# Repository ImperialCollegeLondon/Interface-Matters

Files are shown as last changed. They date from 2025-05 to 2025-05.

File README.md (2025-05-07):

# Interface Matters
This is the repository for paper "**Interface Matters: Comparing First and Third-Person Perspective Interfaces for Bi-Manual Robot Shoe Lacing Behavioural Cloning**" accepted for publication on the 2025 IEEE International Conference on Robotics and Automation (ICRA).

## Demo: Shoe Lacing with GuMi
This demo tests GuMi under the scenario of shoe lacing. The video is replayed at 16x speed.

https://github.com/user-attachments/assets/7c5b7bba-3eb4-41c3-b969-fab2bfed8b5f

## Repo structure
The repository is organized as follows:
- [`gumi/`](gumi/): Contains the 3D models and assembly instructions for the GuMi teleoperation device.
- [`gumi_docker/`](gumi_docker/): Contains the ROS package for GuMi, including the scripts for calibration to publishing ROS commands.

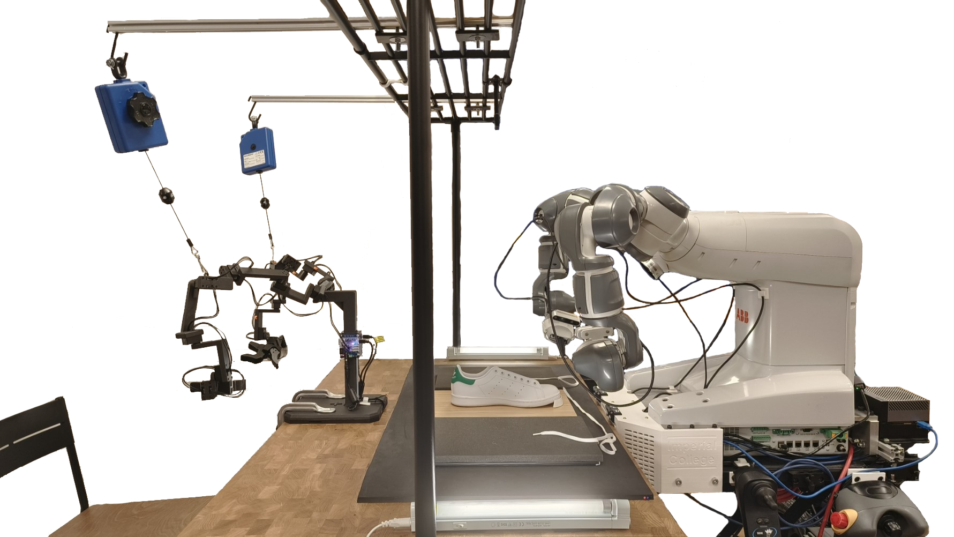
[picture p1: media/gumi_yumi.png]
GuMi Logo


**Note**: This device relies on the [**Externally Guided Motion (EGM)**](https://library.e.abb.com/public/726b2f1b18b24edd8599bfd4eb885553/3HAC073319%20AM%20Externally%20Guided%20Motion%20RW6-en.pdf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) library from ABB. Please check first if EGM is available in your Robotware.

## Acknowledgements
We would like to thank the authors of the following projects for their open-source contributions:
- [GELLO](https://wuphilipp.github.io/gello_site/)
- [kth-yumi](https://github.com/kth-ros-pkg/yumi)
- [abb_robot_driver](https://github.com/ros-industrial/abb_robot_driver)
- [abb_robot_driver_interfaces](https://github.com/ros-industrial/abb_robot_driver_interfaces)
- [abb_libegm](https://github.com/ros-industrial/abb_libegm)
- [abb_librws](https://github.com/ros-industrial/abb_librws)
- [abb_egm_rws_managers](https://github.com/ros-industrial/abb_egm_rws_managers)

## Citation
```
@inproceedings{luo2025interface,
    title={Interface Matters: Comparing First and Third-Person Perspective Interfaces for Bi-Manual Robot Shoe Lacing Behavioural Cloning},
    author={Haining Luo, Rodrigo Chacon Quesada, Fernando Estevez Casado, Nico Lingg, Yiannis Demiris},
    booktitle={2025  IEEE International Conference on Robotics and Automation (ICRA)},
    pages={in print},
    year={2025},
    organization={IEEE}
}
```

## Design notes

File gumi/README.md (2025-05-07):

## GuMi: A teleoperation device for the dual-arm robot YuMi

<p align="center">
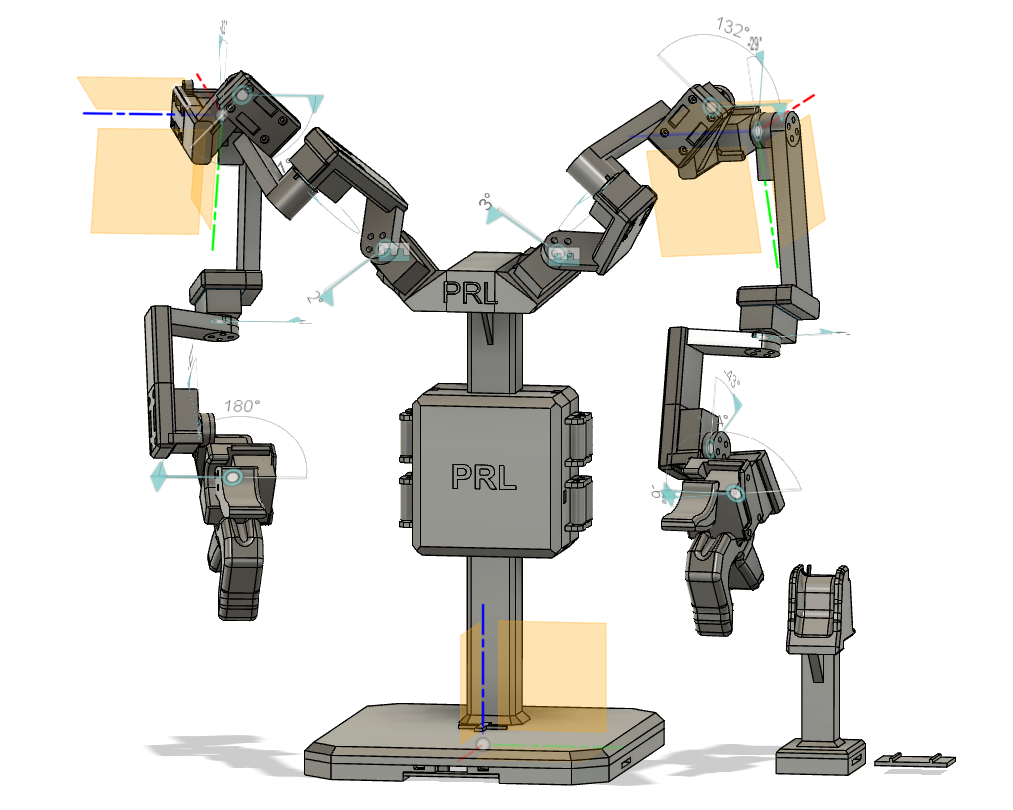
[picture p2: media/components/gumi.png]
GuMi Logo
    
</p>

This folder contains the stl files and assembly instructions for the GuMi teleoperation device. The complete device is composed of the following 3D printed parts:

- 1x [Base](base/README.md)
- 2x [H2D2 Support](h2d2_support/README.md)
- 1x [H2D2 Cover (Optional)](h2d2_cover/README.md)
- 2x [Arm](arm/README.md)
- 2x [Gripper](gripper/README.md)

Additionally, the following hardware is required:
- 2x H2D2 with Power Hub Board
- 14x Dynamixel XL330-M288-T
- 2x Dynamixel XL330-M077-T
- 2x RS PRO 24W AC/DC Adapter 5V DR Output (or equivalent power supply)
- 2x Aeromotive RB2 Tool Balancer (0.5-0.9kg)
- 1x Kennedy 200mm F-Clamp (or equivalent clamp)

You can start from the [Base](base/README.md).

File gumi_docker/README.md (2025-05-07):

# GuMi Scripts
This folder contains dockerfied environment for GuMi. `gumi_ros` package communicates with GuMi and publishes the commands to the robot.  

## EGM
GuMi ROS relies on [Externally Guided Motion (EGM)](https://search.abb.com/library/Download.aspx?DocumentID=3HAC073319-001&DocumentPartId=) from ABB to control YuMi. Check with your local ABB representative to obtain the EGM license for YuMi.
To install the EGM package on the robot controller 
1. Connect YuMi to a Windows device running RobotStudio. Backup the current controller before proceeding.
1. Navigate to Installation->RobotWare->YuMi Controller->Next->Add-> select EGM license file. Be aware that this will remove all existing programs on the robot controller.
1. The robot controller will restart after the installation.

## Configure the drivers for YuMi
GuMi ROS relies on `abb_robot_driver` for communication with the robot. In case this is not completed already, following the steps below to configure the drivers:
1. Install the `state_machine` add-on on the robot controller through RobotStudio. 
   - The `state_machine` add-on was once removed from RoboApps. In case this happens again, download the add-on from [here](https://github.com/ros-industrial/abb_libegm/files/10754679/ABB.StateMachine-1.1.zip).
1. Configure YuMi in RobotStudio 
    - The Communication Protocols: make sure the remote addresses for both arms and UCdevice are the address of the remote machine. Use the same remote port for ROB_L and UCdevice and leave ROB_R alone.
    - Add YuMi gripper tasks to the robot controller. 
        - Find the RAPID code for the gripper tasks in `yumi_gripper_driver/RAPID/`.
        - Follow the [instructions](https://github.com/kth-ros-pkg/yumi/wiki/Firmware#grippers-and-cameras) from KTH to add the gripper tasks to the robot controller (the RAPID codes are adapted from [their repo](https://github.com/kth-ros-pkg/yumi/wiki), please visit for more information about YuMi).

## Calibrate GuMi
The motor positions of the robot need to be calibrated before running the package. The calibration is done by moving the robot to a known position and recording the motor positions. Once you finish, pop the values to the `gumi_ros/scripts/gello.yaml` file. 

## Running the package
1. Pull YuMi drivers:
    `make pull-drivers`
1. Build the Docker image:
    `make build`
1. Build the ROS packages:
    `make compile`
1. Start YuMi positional controller:
    `make pos-controller`
1. Start GELLO interface:
    `make gumi`
    - YuMi will start moving to and stop at the grasp configuration. Now you can check and make sure that GELLO joints are aligned with YuMi. You can hit enter once you are satisfied with the alignment.
    - The robot will move to align with the GELLO model. Once the robot stops, you can hit enter to start the teleoperation.
1. Move the robot back to the grasp position:
    `make yumi-go-grasp`
1. Move the robot to the home position:
    `make yumi-go-home`

<!-- 
# Teleoperation

## Constructing Gello models
TODO: upload the `read_urdf.py` script
1. Use the `read_urdf.py` script to find the shortest link and compare it with the length of the motors
1. Decide on the scale of the model and set the scale in the `read_urdf.py` script
1. Use the `read_urdf.py` script to print the joint Cartesian positions relative to the upper stream joint frame.
    * Set all joints to zero so that it is easier to move from one joint to the next
1. Construct / download models of the motors
1. Set motor positions to the joint positions obtained from the `read_urdf.py` script
    * Double check that the motor axis is the same as the joint axis in RViz
1. Build model holders and align them with the motors
1. Connect the motor holders
1. Add virtual joints to the motor holders

## Gravity Compensation
1. Cannot be done the same as in Gello. YuMi links do not have square angles and the gravity compensation is not as simple as in Gello
1. [Aloha 2](https://aloha-2.github.io/) uses spring balancers to compensate for the gravity as in this [photo](https://aloha-2.github.io/assets/workcell_render.png).
1. The spring balancers they used should be this [AER-RB2](https://www.aero-motivedirect.com/Products/Retractors/?cart_id=UQRuD5LLhNl6haXxaNbuuhn6wPYBaSZ2&user_id=) from Aero-Motive. The company only ships to US addresses. Purchase link [here](https://www.cromwell.co.uk/shop/cutting-tools/tool-balancers/rb2-tool-balancer-0-5-0-9-kg/p/CTL2807800A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) from Cromwell. Datasheet [here](https://www.aero-motivedirect.com/Products/Positioners/PDF/Balancers%20and%20Tool%20Support%20Catalog.pdf)
1. The RB2 balancers are a bit tricky to set up. It needs to be pulled very hard when increasing the tension.

 -->

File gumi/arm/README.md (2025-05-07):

## Arm

<p align="center">
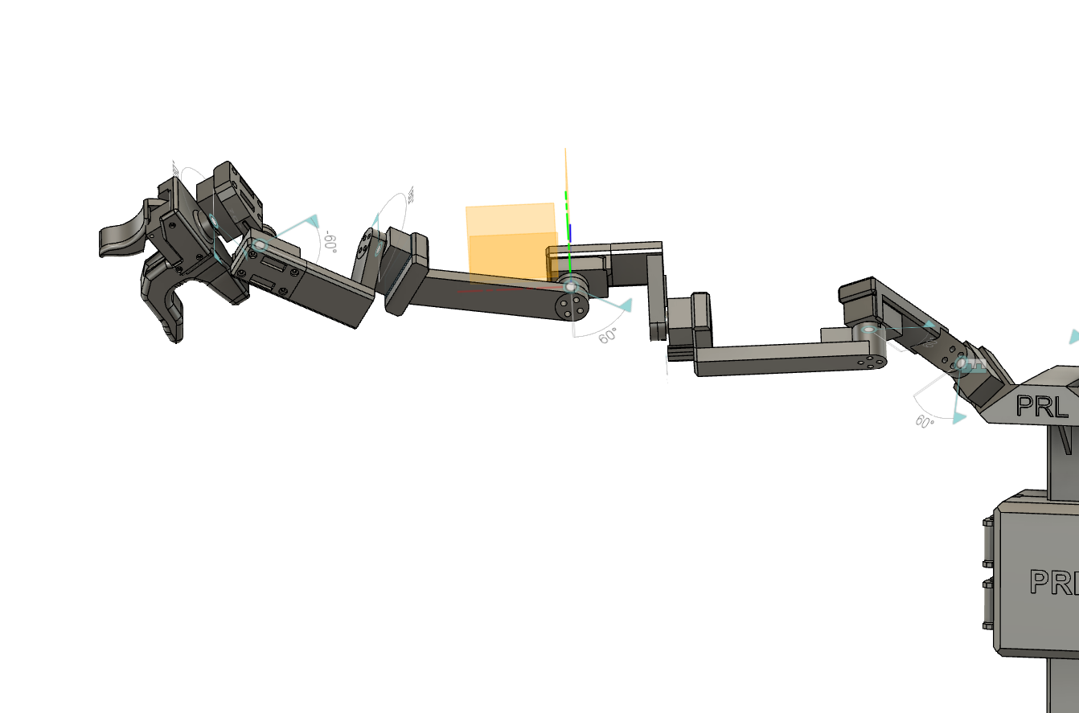
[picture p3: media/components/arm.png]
Arm
    
</p>

This folder includes the 3D models and assembly instructions for the 2 arms of the GuMi teleoperation device. 

### Components
- 1x Link 1-6 (Link 7 is combined with the gripper)
- 7x Dynamixel XL330-M288-T

### Assembly Instructions
1. Start from the base of the arm, install the Dynamixel XL330-M288-T and the links in order.
2. Connect the Dynamixel XL330-M288-T motors using the provided cables. The connected ports do not matter.
3. Move on to install the [Gripper](../gripper/README.md) on the end of the arm.

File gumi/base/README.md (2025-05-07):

## Base

<p align="center">
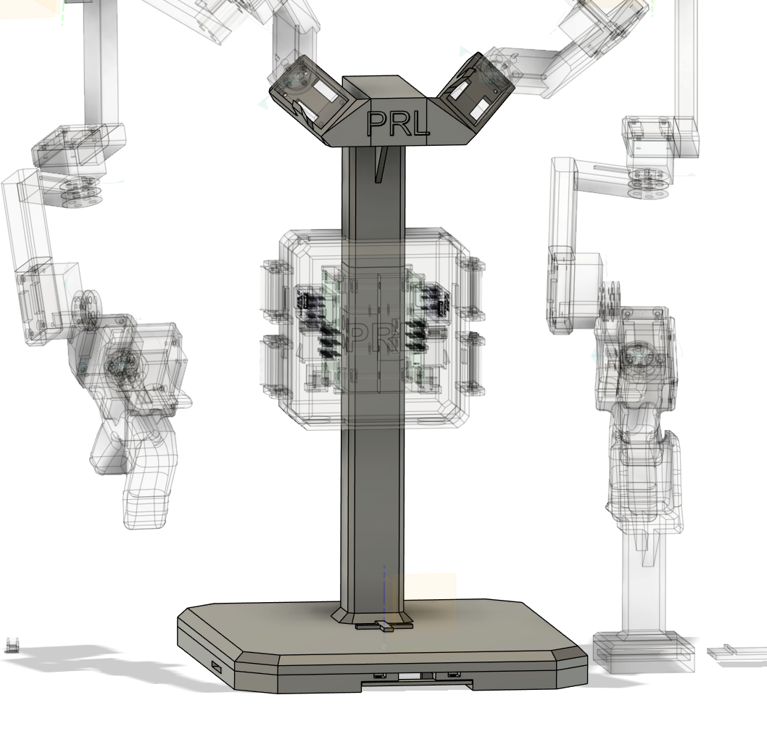
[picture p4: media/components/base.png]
Base Component
    
</p>

The Base component provides support for the two arms, route for the wires at the bottom, and cursor for the base centre. The H2D2 support is mounted on the middle of the base. The wiring box is press-fitted to cover the wires and the H2D2 boards. 

### Components
- 1x BaseBottom
- 1x BaseTop
- 4x M3x15 screws
- 4x M3 nuts

### Assembly Instructions
1. (Optional) Place the BaseBottom side up, glue the two BaseSupports to the BaseBottom in the same orientation as shown in the image. Fit the H2D2 cables though the BaseSupports and Screw the BaseSupportBridge (The BaseSupports are for asthetic purposes only and not necessary for the structure of the base).
2. Place the BaseTop on top of the BaseBottom and align the holes. Insert 4 M3x15 screws through the holes and knot the screws with M3 nuts.
3. Move on to install the [H2D2 Supports](../h2d2_support/README.md).

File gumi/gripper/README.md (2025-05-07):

## Gripper

The gripper design is a slightly modified version from the original GELLO project. Please refer to the [GELLO](https://wuphilipp.github.io/gello_site/) project for more information.

<p align="center">
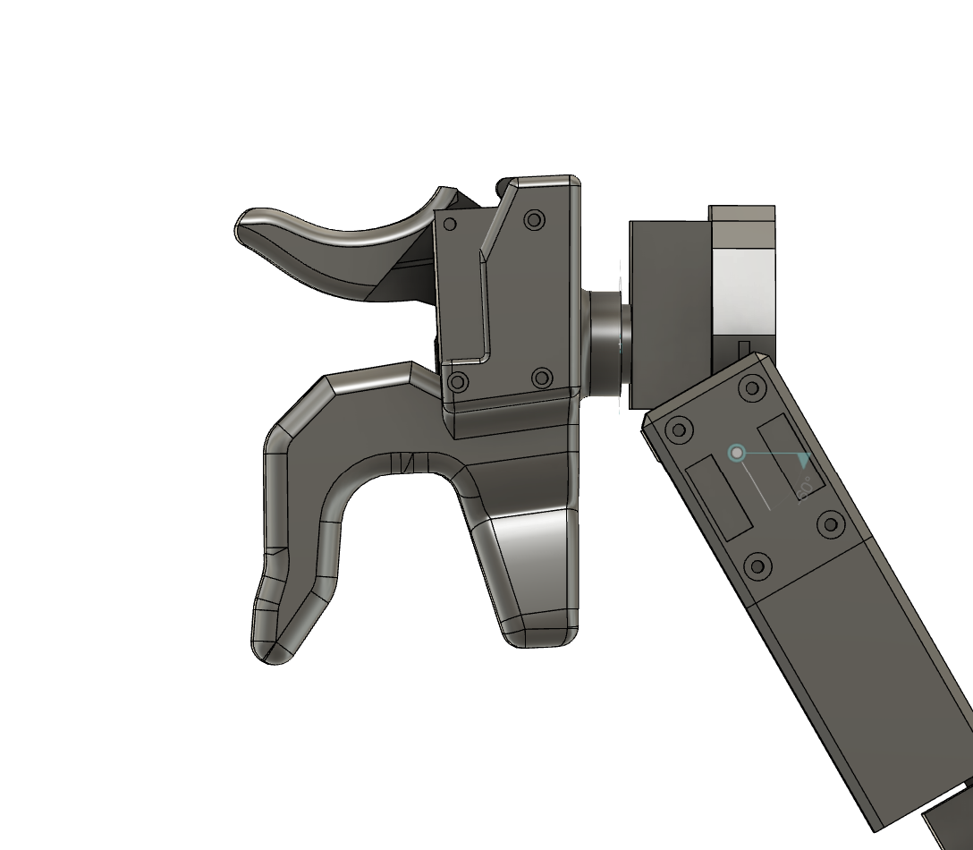
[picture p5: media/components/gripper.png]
Gripper
    
</p>

The Gripper component provides the ability to control the opening and closing of YuMi's SmartGripper. 

### Components
- 1x GripperBase
- 1x GripperTrigger
- 1x Dynamixel XL330-M077-T

### Assembly Instructions
1. Install the GripperBase on the end of the arm using the provided motor screws.
2. Install the Dynamixel XL330-M077-T on the GripperTrigger using the motor screws.
3. Connect the Dynamixel XL330-M077-T motor to the GripperBase using the motor screws.
4. Connect the motor provided cables to the Dynamixel XL330-M077-T motor with the Joint 7 motor.
5. (Optional) Move on to install the [H2D2 Cover](../h2d2_cover/README.md).

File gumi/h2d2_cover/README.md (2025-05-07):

## H2D2 Cover

<p align="center">
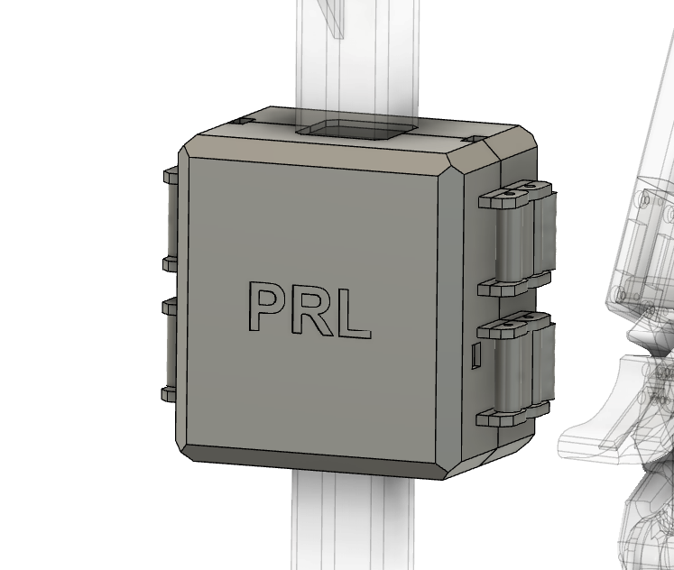
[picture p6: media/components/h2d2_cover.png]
Base Component
    
</p>

The H2D2Cover component seals electrical circuits and wires inside for the safety and aesthetics purposes. It is mounted on the middle of the base. 

### Components
- 1x H2D2CoverFront
- 1x H2D2CoverBack
- 4x H2D2CoverLatch
- 8x M3x20 screws

### Assembly Instructions
1. Place the latches on the H2D2CoverFront slots with the holes aligned as shown in the image. Insert screws through the holes of the H2D2CoverFront and H2D2CoverBack.
1. Place the H2D2CoverFront outside the H2D2Support and align the cable holes.
1. Close the latches to secure the H2D2CoverFront and H2D2CoverBack together.
1. Connect the USB and power cables to the H2D2 Power Hub Board.

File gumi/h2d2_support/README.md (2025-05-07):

## H2D2 Support

<p align="center">
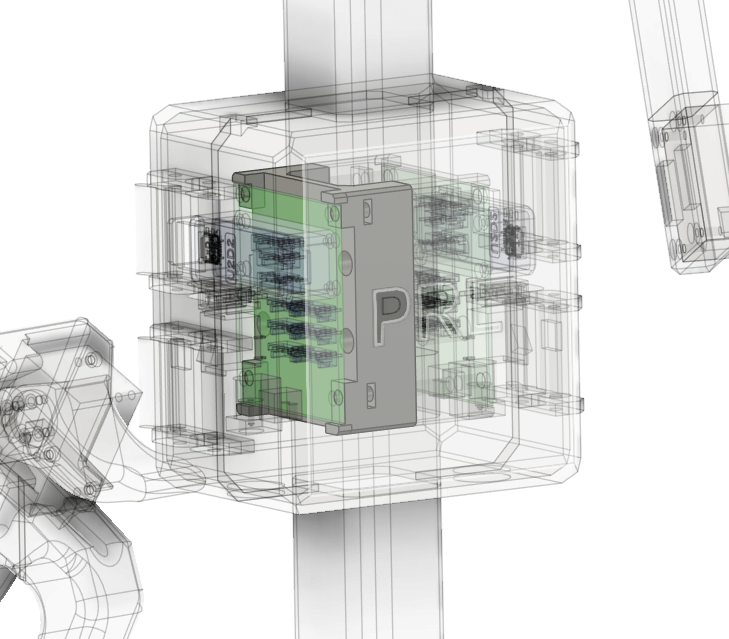
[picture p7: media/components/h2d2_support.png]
Base Component
    
</p>

The H2D2Support component provides support for the H2D2 boards. The H2D2Support is mounted on the middle of the base. 

### Components
- 2x H2D2Support
- 4x M3x15 screws
- 4x M3 nuts

### Assembly Instructions
1. Place the H2D2Support outside the Base piller and align the holes. 
1. Position the H2D2 Power Hub Board on the H2D2Support and align the holes.
1. Insert 4 M3x15 screws through the holes and knot the screws with M3 nuts.
1. If not using the H2D2 Cover, connect the USB and power cables to the H2D2 Power Hub Board.
1. Make sure the two USB cables connecting the H2D2s are connected to the device running GuMi scripts. If using a laptop, consider using a powered USB hub in case of insufficient motherboard power supply.
1. Move on to install the [Arms](../arm/README.md).

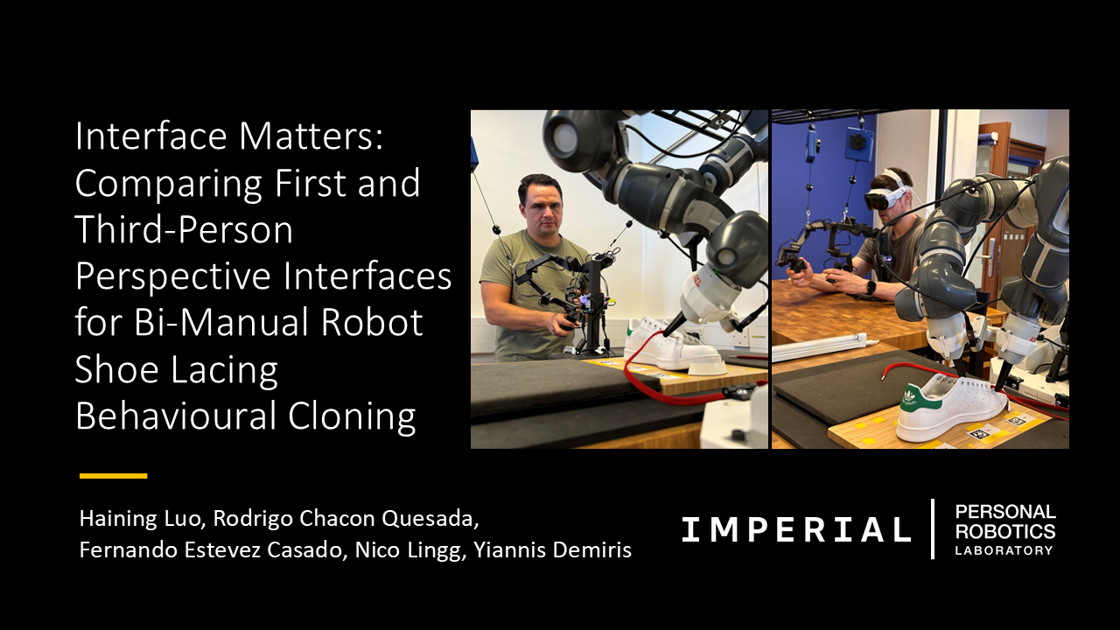
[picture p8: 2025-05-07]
media/cover_page.png

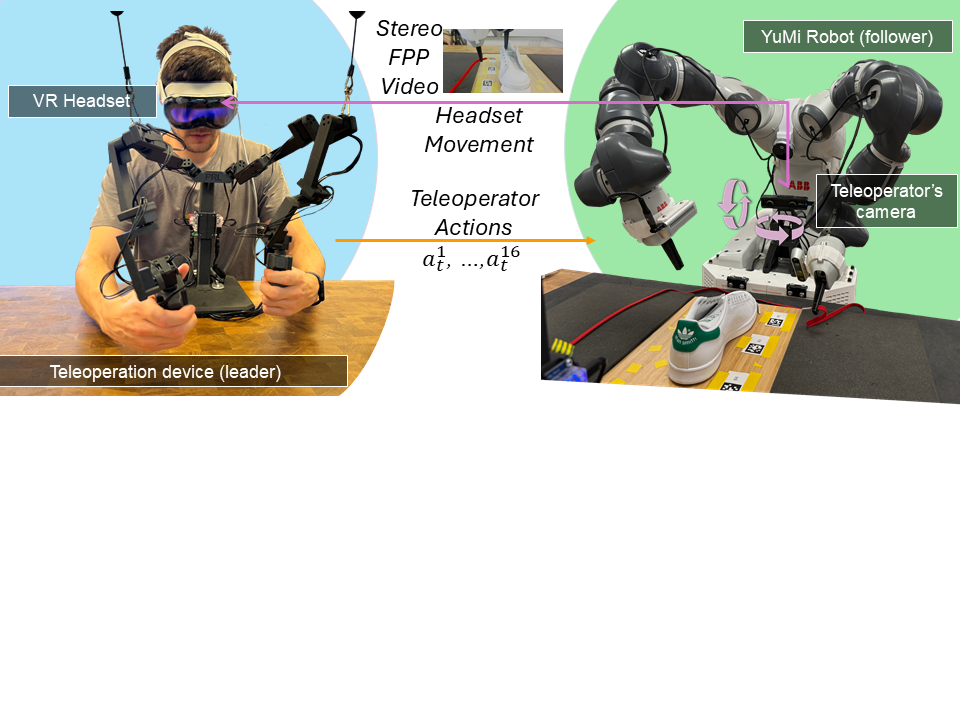
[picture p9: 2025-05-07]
media/ego_gumi_structure.png

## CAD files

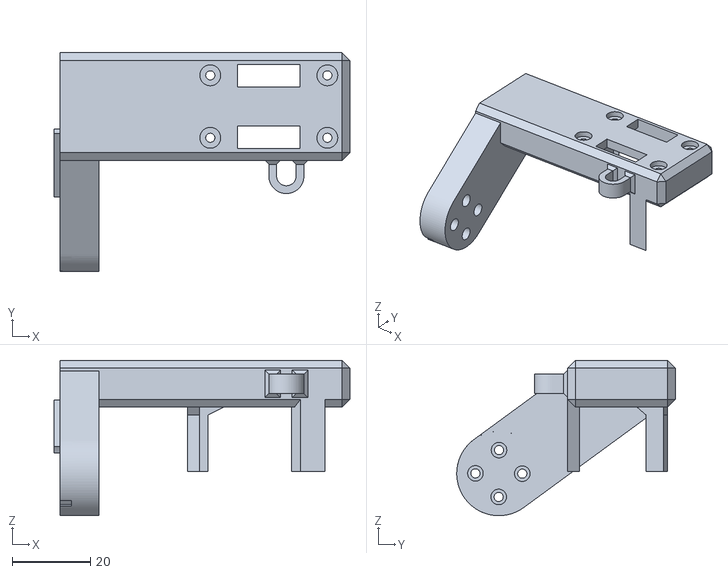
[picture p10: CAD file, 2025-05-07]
gumi/arm/stl/Link3.stl
75.8 x 56.0 x 39.8

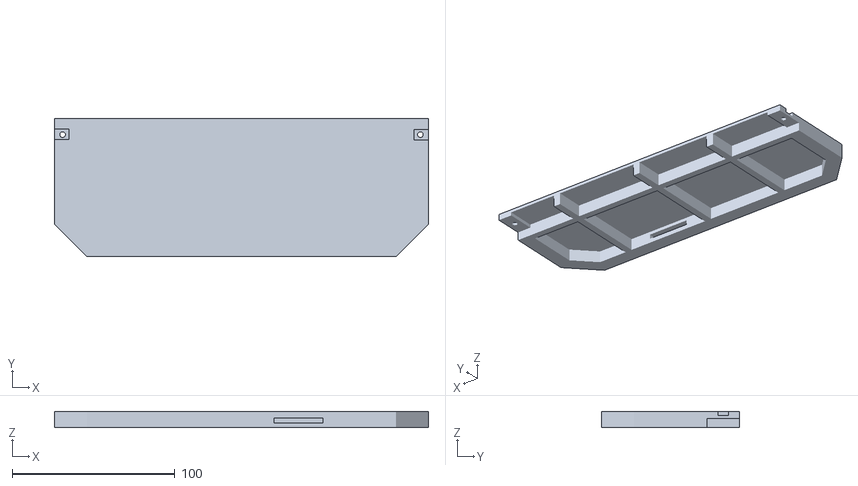
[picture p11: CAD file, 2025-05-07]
gumi/base/stl/BaseSupport.stl
230.0 x 85.0 x 10.0

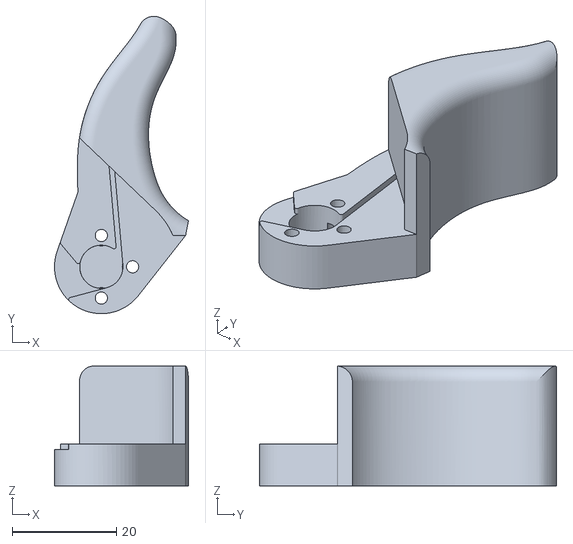
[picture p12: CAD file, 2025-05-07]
gumi/gripper/stl/GripperTrigger.stl
25.7 x 57.0 x 23.0

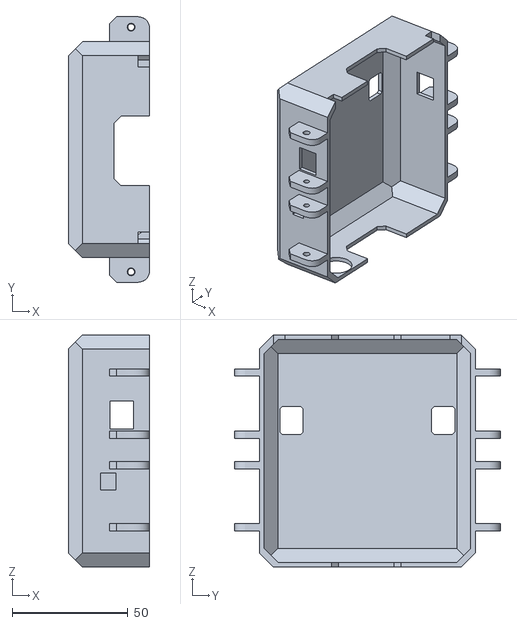
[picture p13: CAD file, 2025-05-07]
gumi/h2d2_cover/stl/H2D2CoverBack.stl
35.0 x 114.7 x 100.0

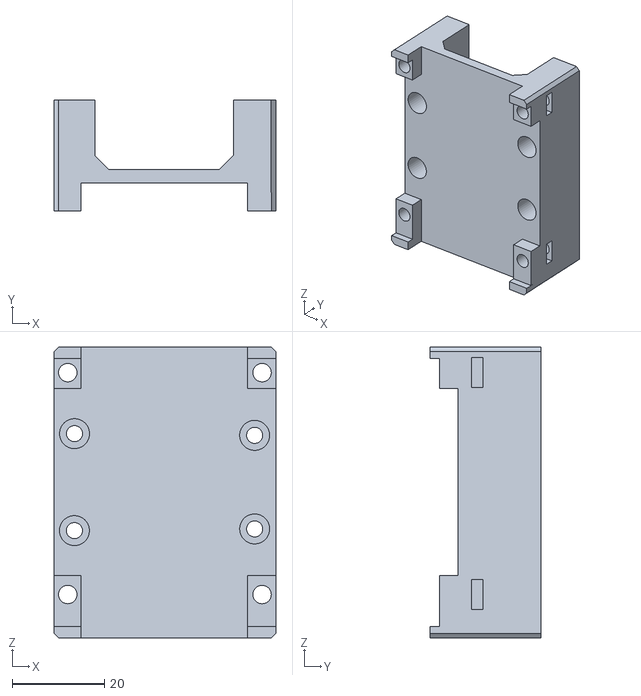
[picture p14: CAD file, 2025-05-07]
gumi/h2d2_support/stl/H2D2_Support.stl
48.0 x 24.0 x 63.0

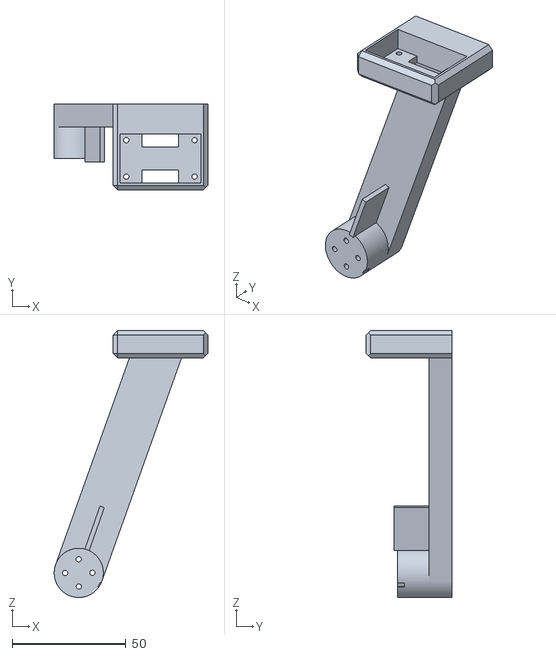
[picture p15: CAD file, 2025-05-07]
gumi/arm/stl/Link4.stl
67.5 x 37.6 x 117.3

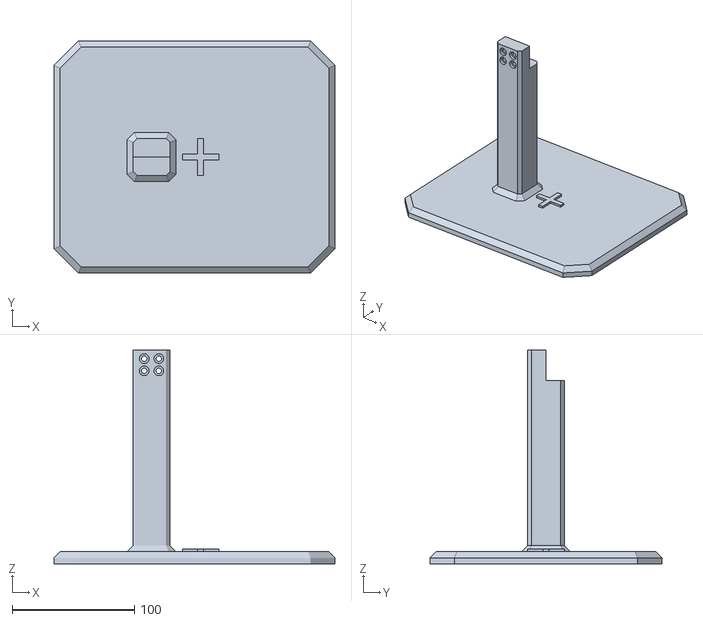
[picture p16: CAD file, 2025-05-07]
gumi/base/stl/BaseBottom.stl
230.0 x 190.0 x 175.0

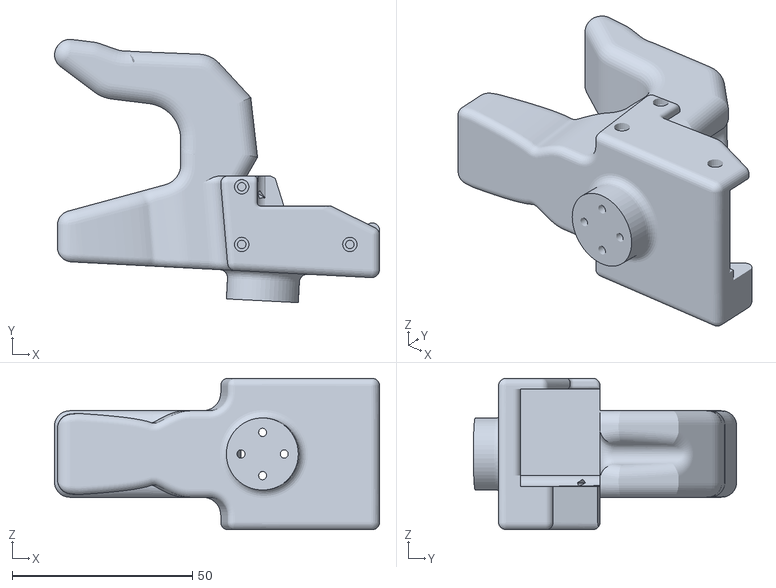
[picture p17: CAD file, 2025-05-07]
gumi/gripper/stl/GripperBase.stl
90.2 x 73.1 x 42.0

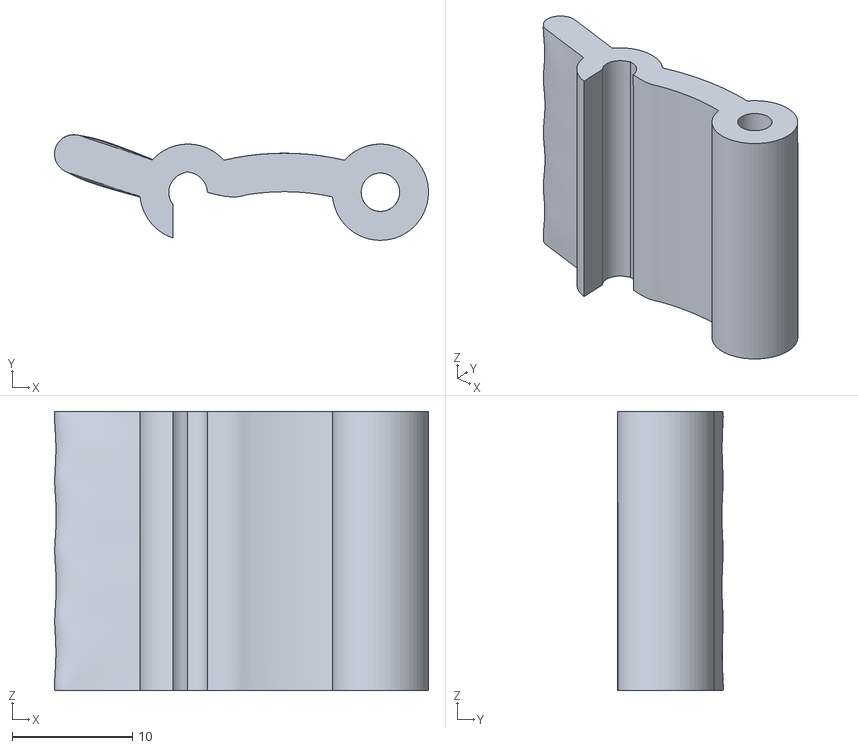
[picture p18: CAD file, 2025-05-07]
gumi/h2d2_cover/stl/H2D2CoverLatch.stl
31.1 x 8.79 x 23.2

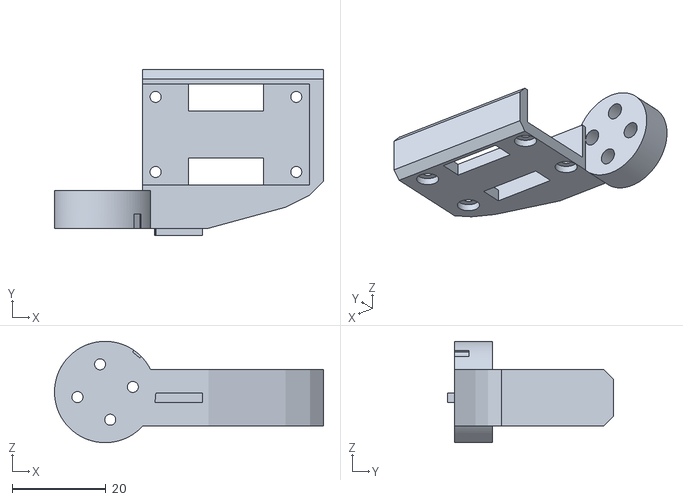
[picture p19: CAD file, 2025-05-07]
gumi/arm/stl/Llink6.stl
57.3 x 35.3 x 21.6

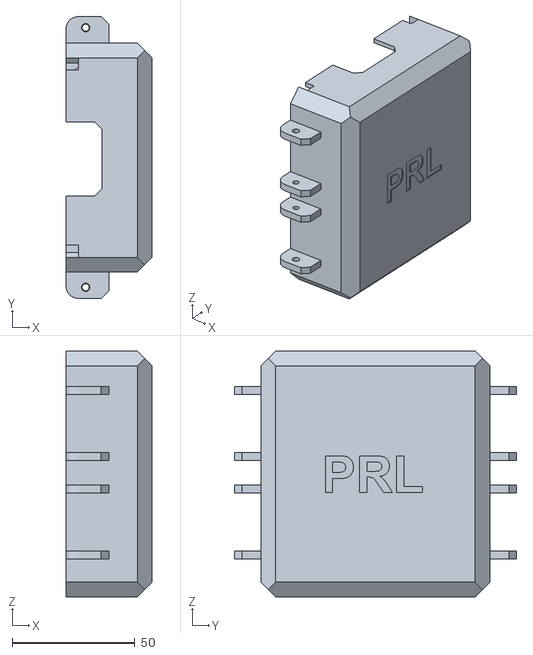
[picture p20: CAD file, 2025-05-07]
gumi/h2d2_cover/stl/H2D2CoverFront.stl
35.0 x 114.7 x 100.0

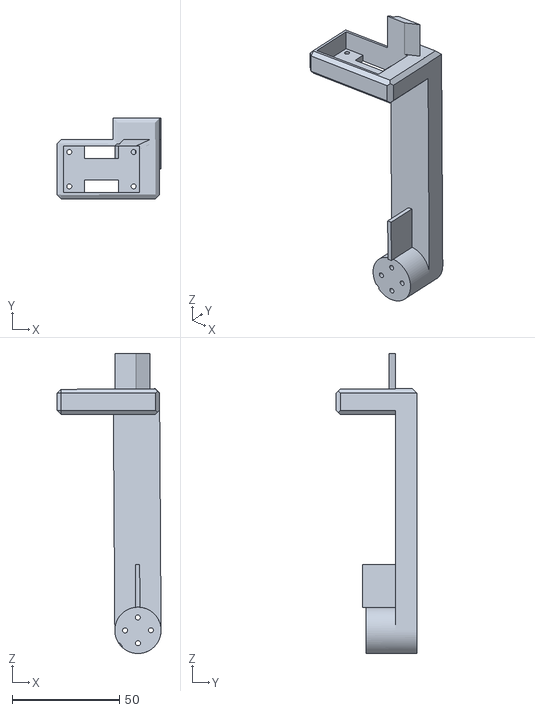
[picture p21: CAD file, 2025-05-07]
gumi/arm/stl/Link2.stl
48.6 x 37.6 x 139.9

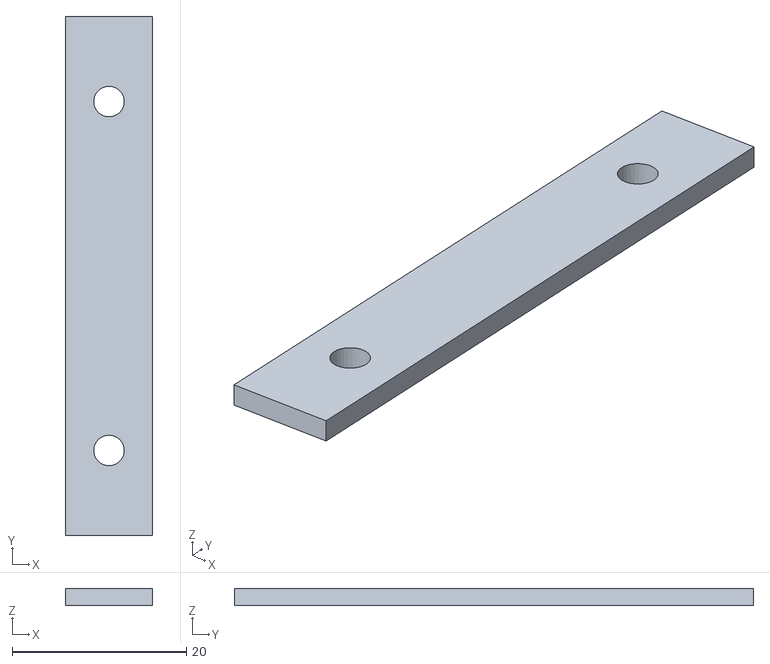
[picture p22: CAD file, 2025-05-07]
gumi/base/stl/BaseSupportBridge.stl
10.0 x 59.5 x 2.00

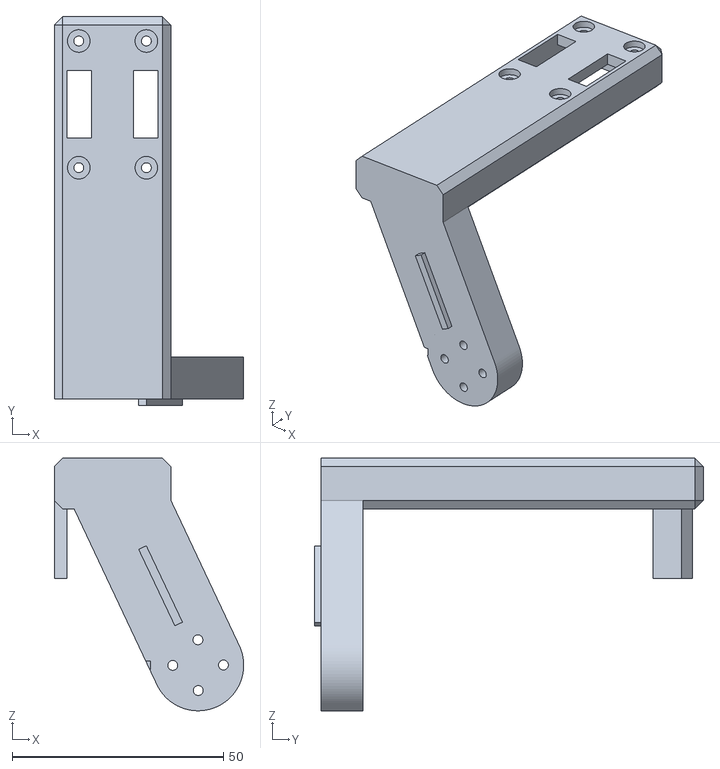
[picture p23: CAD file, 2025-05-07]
gumi/arm/stl/Link5.stl
44.8 x 92.1 x 59.8

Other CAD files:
gumi/base/stl/BaseSupport2.stl
gumi/base/stl/BaseTop.stl
gumi/arm/stl/Link1.stl

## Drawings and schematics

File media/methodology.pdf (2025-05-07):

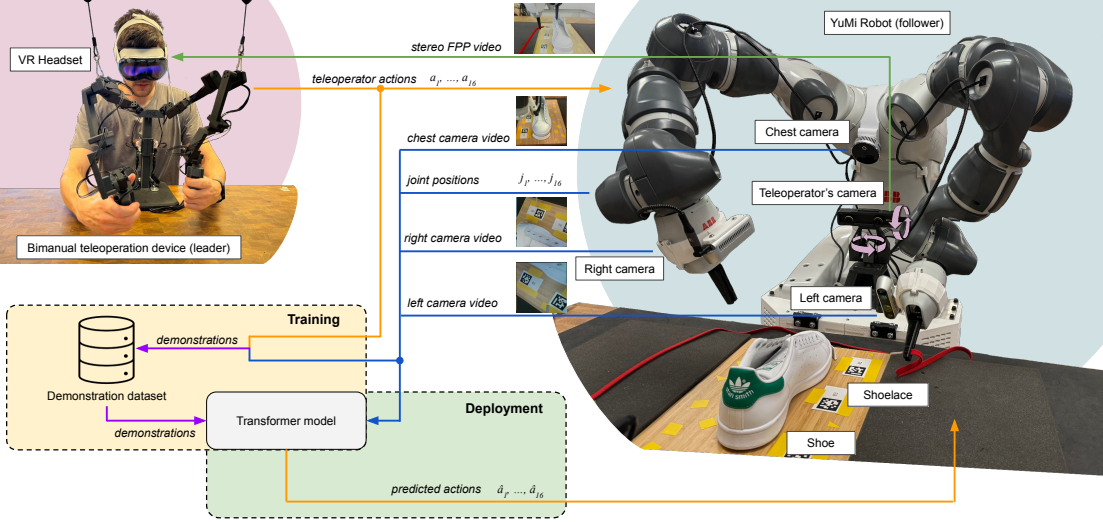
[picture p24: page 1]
VR Headset; Training; Right camera; Left camera; Transformer model; Deployment; Shoe; Shoelace; teleoperator actions; Demonstration dataset; predicted actions; Teleoperator’s camera; joint positions; demonstrations

YuMi Robot (follower)

stereo FPP video

Chest camera chest camera video

right camera video

Bimanual teleoperation device (leader)

left camera video

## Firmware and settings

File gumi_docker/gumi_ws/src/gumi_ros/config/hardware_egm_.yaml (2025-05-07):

# These settings must match:
# - Port numbers specified in the ABB robot controller's system configurations for EGM communication.
# - Names of the mechanical unit groups intended to be controlled by respective EGM communication channel.
egm:
  channel_1:
    port_number: 6510
    mech_unit_group: "rob_l"
  channel_2:
    port_number: 6512
    mech_unit_group: "rob_r"

# These settings must match:
# - Joint names extracted from the ABB robot controller.
# - The 'yumi_' prefix must match the nickname/identifier,
#   which is set in the corresponding launch file.
#
# See http://wiki.ros.org/joint_limits_interface for more info about available joint limits:
joint_limits:
  yumi_robl_joint_1:
    min_position: -2.84
    max_position: 2.84
    has_velocity_limits: true
    max_velocity: 1.570796327
    has_acceleration_limits: false
    max_acceleration: 0
  yumi_robr_joint_1:
    min_position: -2.84
    max_position: 2.84
    has_velocity_limits: true
    max_velocity: 1.570796327
    has_acceleration_limits: false
    max_acceleration: 0
  yumi_robl_joint_2:
    min_position: -2.4
    max_position: 0.65
    has_velocity_limits: true
    max_velocity: 1.570796327
    has_acceleration_limits: false
    max_acceleration: 0
  yumi_robr_joint_2:
    min_position: -2.4
    max_position: 0.65
    has_velocity_limits: true
    max_velocity: 1.570796327
    has_acceleration_limits: false
    max_acceleration: 0
  yumi_robl_joint_3:
    min_position: -2
    max_position: 1.29
    has_velocity_limits: true
    max_velocity: 1.570796327
    has_acceleration_limits: false
    max_acceleration: 0
  yumi_robr_joint_3:
    min_position: -2
    max_position: 1.29
    has_velocity_limits: true
    max_velocity: 1.570796327
    has_acceleration_limits: false
    max_acceleration: 0
  yumi_robl_joint_4:
    min_position: -4.9
    max_position: 4.9
    has_velocity_limits: true
    max_velocity: 1.570796327
    has_acceleration_limits: false
    max_acceleration: 0
  yumi_robr_joint_4:
    min_position: -4.9
    max_position: 4.9
    has_velocity_limits: true
    max_velocity: 1.570796327
    has_acceleration_limits: false
    max_acceleration: 0
  yumi_robl_joint_5:
    min_position: -1.43
    max_position: 2.3
    has_velocity_limits: true
    max_velocity: 1.570796327
    has_acceleration_limits: false
    max_acceleration: 0
  yumi_robr_joint_5:
    min_position: -1.43
    max_position: 2.3
    has_velocity_limits: true
    max_velocity: 1.570796327
    has_acceleration_limits: false
    max_acceleration: 0
  yumi_robl_joint_6:
    min_position: -3.89
    max_position: 3.89
    has_velocity_limits: true
    max_velocity: 1.570796327
    has_acceleration_limits: false
    max_acceleration: 0
  yumi_robr_joint_6:
    min_position: -3.89
    max_position: 3.89
    has_velocity_limits: true
    max_velocity: 1.570796327
    has_acceleration_limits: false
    max_acceleration: 0
  yumi_robl_joint_7:
    min_position: -2.84
    max_position: 2.84
    has_velocity_limits: true
    max_velocity: 1.570796327
    has_acceleration_limits: false
    max_acceleration: 0
  yumi_robr_joint_7:
    min_position: -2.84
    max_position: 2.84
    has_velocity_limits: true
    max_velocity: 1.570796327
    has_acceleration_limits: false
    max_acceleration: 0

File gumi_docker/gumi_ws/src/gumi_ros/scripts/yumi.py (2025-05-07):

from typing import Dict

import numpy as np
from math import sqrt
from random import random

import rospy
from std_msgs.msg import Float64, Float64MultiArray
from sensor_msgs.msg import JointState

from abb_robot_msgs.srv import TriggerWithResultCode
from abb_egm_msgs.msg import EGMState
from controller_manager_msgs.srv import SwitchController, SwitchControllerRequest
from abb_rapid_sm_addin_msgs.srv import GetEGMSettings, SetEGMSettings

# from base_robot import Robot


class YuMi():
    GRIPPER_TOLERANCE = 0.5 # mm
    TIME_TOLERANCE = 50
    GRIPPER_TIME_TOLERANCE = 5

    keep_egm_alive = False

    left_rapid_task = 'T_ROB_L'
    right_rapid_task = 'T_ROB_R'
    joint_names = ['yumi_robr_joint_1', 'yumi_robr_joint_2', 'yumi_robr_joint_3', 'yumi_robr_joint_4', 
                   'yumi_robr_joint_5', 'yumi_robr_joint_6', 'yumi_robr_joint_7', 'yumi_robl_joint_1', 
                   'yumi_robl_joint_2', 'yumi_robl_joint_3', 'yumi_robl_joint_4', 'yumi_robl_joint_5',
                   'yumi_robl_joint_6', 'yumi_robl_joint_7', 'gripper_r_joint', 'gripper_r_joint_m',
                   'gripper_l_joint', 'gripper_l_joint_m']
    
    # fix the left arm and gripper joints
    left_calc_states = [0, -2.2689, 2.3562, 0.5236, 0, 0.6981, 0]
    right_calc_states = [0, -2.2689, -2.3562, 0.5236, 0, 0.6981, 0]
    right_obs_states_old = [1.3764188289642334, -0.5266491770744324, -2.042018175125122, -0.25265806913375854, 0.39488810300827026, 1.015584111213684, 2.192312002182007]
    left_obs_states_old = [-1.2257874011993408, -0.4985324442386627, 1.980921745300293, -0.058894701302051544, -0.47677695751190186, 0.9440299868583679, -2.054021120071411]
    left_obs_states = [-0.720012903213501, -0.3579239249229431, 1.772327184677124, 
                       0.13136780261993408, -0.648350715637207, 1.1232486963272095, 
                       -1.8344221115112305]
    right_obs_states = [0.8814099431037903, -0.36250463128089905, -1.85231351852417, 
                        -0.028060272336006165, 0.606028139591217, 1.1636393070220947, 
                        1.9661468267440796]
    left_grasp_states = [-0.6087591438289535, -1.082181434487124, 1.8366249441652813, 
                         0.5307080841282654, 2.619130781460849, 0.30367070501132487, 
                         2.0107517372984773] 
    right_grasp_states = [0.6849933284549622, -1.0505161162309455, -1.9075465218907455, 
                          0.48255300503453435, 0.3831120013800615, -0.28755738199385494, 
                          1.3071448436156516]
    left_grasp_states2 = [-1.0771714448928833, -0.7815413475036621, 1.3724327087402344,
                            0.3715556263923645, 1.7982889413833618, 0.8510035872459412,
                            2.2453041076660156]
    right_grasp_states2 = [1.0602233409881592, -0.6867497563362122, -1.4237779378890991, 
                           0.3548184633255005, 4.543345928192139, 0.7604496479034424, 
                           -2.2329251766204834]

    command_pub = rospy.Publisher('/yumi/egm/joint_group_position_controller/command', Float64MultiArray, queue_size=10)
    left_gripper_pos_pub = rospy.Publisher('/yumi/gripper_l_position_cmd', Float64, queue_size=10)
    right_gripper_pos_pub = rospy.Publisher('/yumi/gripper_r_position_cmd', Float64, queue_size=10)
    left_gripper_cmd_pub = rospy.Publisher('/yumi/gripper_l_effort_cmd', Float64, queue_size=10)
    right_gripper_cmd_pub = rospy.Publisher('/yumi/gripper_r_effort_cmd', Float64, queue_size=10)

    def __init__(self):
        ### Prepare the robot for teleoperation
        self.start_egm_joint_client = rospy.ServiceProxy('/yumi/rws/sm_addin/start_egm_joint', TriggerWithResultCode)
        self.stop_egm_joint_client = rospy.ServiceProxy('/yumi/rws/sm_addin/stop_egm', TriggerWithResultCode)
        self.switch_controller_client = rospy.ServiceProxy('/yumi/egm/controller_manager/switch_controller', SwitchController)
        self.get_egm_settings = rospy.ServiceProxy("/yumi/rws/sm_addin/get_egm_settings", GetEGMSettings)
        self.set_egm_settings = rospy.ServiceProxy("/yumi/rws/sm_addin/set_egm_settings", SetEGMSettings)
        rospy.Subscriber('/yumi/egm/joint_states', JointState, self.yumi_states_sb, queue_size=1)
        rospy.Subscriber('/yumi/egm/egm_states', EGMState, self.egm_state_cb)
        rospy.Subscriber('/yumi/gripper_states', JointState, self.yumi_gripper_states_sb, queue_size=1)

        # get initial states
        states = rospy.wait_for_message('/yumi/egm/joint_states', JointState)
        self.left_arm_state = states.position[:7]
        self.right_arm_state = states.position[7:14]
        self.left_velocities = states.velocity[:7]
        self.right_velocities = states.velocity[7:14]
        gripper_states = rospy.wait_for_message('/yumi/gripper_states', JointState)
        self.left_gripper_state = gripper_states.position[0]*1000
        self.right_gripper_state = gripper_states.position[1]*1000
        rospy.sleep(0.5)
        print("YuMi wrapper initialized")

    def start_egm(self):
        response = self.start_egm_joint_client()
        if response.result_code == 1:
            print("EGM started")
        else:
            print("Failed to start EGM (code: {}, message: {})".format(response.result_code, response.message))
        rospy.sleep(0.5)
    
    def stop_egm(self):
        response = self.stop_egm_joint_client()
        if response.result_code == 1:
            print("EGM stopped")
        else:
            print("Failed to stop EGM (code: {}, message: {})".format(response.result_code, response.message))
        rospy.sleep(0.5)


    def egm_state_cb(self,msg):
        if not self.keep_egm_alive:
            return
        # check if EGM is off
        if msg.egm_channels[0].active == False:
            self.restarting = True
            rospy.loginfo('EGM is off. Restarting...')
            # call the service to start the EGM
            response = self.start_egm_joint_client()
            if response.result_code == 1:
                rospy.loginfo('EGM restarted successfully.')
            else:
                rospy.logerr('Failed to restart EGM (code: {}, message: {})'.format(
                    response.result_code, response.message))
            self.restarting = False

    def start_controllers(self):
        request = SwitchControllerRequest(start_controllers=['joint_group_position_controller'], 
                                        stop_controllers=[''], 
                                        strictness=1, 
                                        start_asap=False, 
                                        timeout=0.0)
        response = self.switch_controller_client(request)
        if response.ok:
            print("Controller started")
        else:
            print("Failed to restart Controllers (code: {}, message: {})".format(response.result_code, response.message))
        rospy.sleep(0.5)

    def change_max_speed(self, task, max_speed_deviation):
        # reset max velocity
        current_settings = self.get_egm_settings(task=task)
        settings = current_settings.settings
        settings.activate.max_speed_deviation = max_speed_deviation # degs
        settings.run.pos_corr_gain = 1 # 0 for pure velocity control
        response = self.set_egm_settings(task=task, settings=settings)
        if response.result_code == 1:
            print("Max speed deviation set to: ", max_speed_deviation)
        else:
            print("Failed to set max speed deviation (code: {}, message: {})".format(response.result_code, response.message))
        rospy.sleep(0.5)
    
    def _get_eef_pos(self) -> np.ndarray:
        return self.left_gripper_state + self.right_gripper_state

    def _get_gripper_pos(self) -> float:
        return self.left_gripper_state + self.right_gripper_state

    def get_joint_state(self):
        """Get the current state of the leader robot.

        Returns:
            T: The current state of the leader robot.
        """
        return list(self.left_arm_state) + list(self.right_arm_state)
    
    def get_joint_vel(self):
        """Get the current state of the leader robot.

        Returns:
            T: The current state of the leader robot.
        """
        return self.left_velocities + self.right_velocities

    def command_joint_state(self, joint_state: np.ndarray) -> None:
        """Command the leader robot to a given state.

        Args:
            joint_state (np.ndarray): The state to command the leader robot to.
        """
        controller_cmd = Float64MultiArray()
        controller_cmd.data = joint_state
        self.command_pub.publish(controller_cmd)

    def get_observations(self) -> Dict[str, np.ndarray]:
        joint_pos = self.get_joint_state()
        joint_vel = self.get_joint_vel()
        ee_force = self._get_eef_force()
        ee_pos_quat = self._get_eef_pos()
        ee_vel = self._get_eef_speed()
        gripper_pos = np.array([joint_pos[-1]])
        return {
            "joint_positions": joint_pos,
            "joint_velocities": joint_vel,
            "ee_pos_quat": ee_pos_quat,
            "ee_vel": ee_vel,
            "ee_force": ee_force,
            "gripper_position": gripper_pos,
        }

    
    def yumi_states_sb(self, msg):
        """ saves yumi states into this class """
        self.left_arm_state = msg.position[:7]
        self.right_arm_state = msg.position[7:14]
        self.left_velocities = msg.velocity[:7]
        self.right_velocities = msg.velocity[7:14]

    def yumi_gripper_states_sb(self, msg):
        """ saves yumi gripper states into this class """
        self.left_gripper_state = msg.position[0]*1000
        self.right_gripper_state = msg.position[1]*1000

    ###############
    ### Gripper ###
    ###############

    def wait_for_completion_gripper_l(self, log=True):
        """ pause until left gripper state within tolerance """
        time_start = rospy.Time.now()
        while not rospy.is_shutdown() and (rospy.Time.now()-time_start).to_sec()<self.GRIPPER_TIME_TOLERANCE:
            if self.check_completion_gripper_l():
                return True
            else:
                rospy.sleep(0.01)
        if log:
            rospy.logwarn("Gripper action timed-out. Not able to complete in "+str(self.GRIPPER_TIME_TOLERANCE)+'s')
        return False

    def wait_for_completion_gripper_r(self, log=True):
        """ pause until right gripper state within tolerance """
        time_start = rospy.Time.now()
        while not rospy.is_shutdown() and (rospy.Time.now()-time_start).to_sec()<self.GRIPPER_TIME_TOLERANCE:
            if self.check_completion_gripper_r():
                return True
            else:
                rospy.sleep(0.01)
        if log:
            rospy.logwarn("Gripper action timed-out. Not able to complete in "+str(self.GRIPPER_TIME_TOLERANCE)+'s')
        return False

    def check_completion_gripper_l(self):
        """ check if left gripper commands are within tolerance """
        error = sqrt((self.left_gripper_state-self.left_gripper_target)**2)
        return error<=self.GRIPPER_TOLERANCE

    def check_completion_gripper_r(self):
        """ check if right gripper commands are within tolerance """
        error = sqrt((self.right_gripper_state-self.right_gripper_target)**2)
        return error<=self.GRIPPER_TOLERANCE

    def closeRightGripper(self, wait=True, log=False):
        """ Close the right gripper """
        self.sendRightGripperCmd(10, wait, log)

    def openRightGripper(self, wait=True, log=False):
        """ Open the right gripper """
        self.sendRightGripperCmd(-10, wait, log)

    def closeLeftGripper(self, wait=True, log=False): 
        """ Close the left gripper """
        self.sendLeftGripperCmd(10, wait, log)

    def openLeftGripper(self, wait=True, log=False):
        """ Open the right gripper """
        self.sendLeftGripperCmd(-10, wait, log)

    def sendRightGripperCmd(self, cmd, wait=True, log=False):
        """ Send an effort command to the right gripper """
        noise = random()/100
        msg = Float64()
        msg.data = cmd+noise
        self.right_gripper_target = 25 if cmd<0 else 0
        self.right_gripper_cmd_pub.publish(msg)
        if wait and cmd!=0:
            self.wait_for_completion_gripper_r(log=log)

    def sendLeftGripperCmd(self, cmd, wait=True, log=False):
        """ Send an effort command to the left gripper """
        noise = random()/100
        msg = Float64()
        msg.data = cmd+noise
        self.left_gripper_target = 25 if cmd<0 else 0
        self.left_gripper_cmd_pub.publish(msg)
        if wait and cmd!=0:
            self.wait_for_completion_gripper_l(log=log)

    def setRightGripperPos(self, pos, wait=True, log=False): # pos in mm, opening of one side
        """ Send a position command to the right gripper """
        noise = random()/100
        msg = Float64()
        msg.data = self.right_gripper_target = pos+noise
        self.right_gripper_pos_pub.publish(msg)
        if wait:
            self.wait_for_completion_gripper_r(log=log)

    def setLeftGripperPos(self, pos, wait=True, log=False):
        """ Send a position command to the left gripper """
        noise = random()/100
        msg = Float64()
        msg.data = self.left_gripper_target = pos+noise
        self.left_gripper_pos_pub.publish(msg)
        if wait:
            self.wait_for_completion_gripper_l(log=log)


def main():
    rospy.init_node('yumi_wrapper', anonymous=True)
    yumi = YuMi()
    yumi.stop_egm()

    # slow down the speed of the robot
    yumi.change_max_speed(yumi.left_rapid_task, 10) # 5 degrees per second
    yumi.change_max_speed(yumi.right_rapid_task, 10) # 5 degrees per second

    yumi.start_egm()
    yumi.start_controllers()
    
    # move yumi to the initial position
    yumi.command_joint_state(yumi.left_grasp_states + yumi.right_grasp_states)
    key = input("Press Enter when the movement is done")
    if key == 'q':
        exit()
        
    yumi.stop_egm()
    # slow down the speed of the robot
    yumi.change_max_speed(yumi.left_rapid_task, 30) # 5 degrees per second
    yumi.change_max_speed(yumi.right_rapid_task, 30) # 5 degrees per second

    yumi.start_egm()
    yumi.start_controllers()
    print("YuMi ready for teleoperation")


if __name__ == "__main__":
    main()
